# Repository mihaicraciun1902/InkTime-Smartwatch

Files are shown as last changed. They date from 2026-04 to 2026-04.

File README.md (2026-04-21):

# ⌚ InkTime: Open-Source Hackable Smartwatch

**InkTime** is an affordable, open-source smartwatch powered by the Nordic nRF52840 SoC and an ultra-low-power e-paper display. It is designed from the ground up to be highly hackable, easy to manufacture, and power-efficient.

This repository contains all Engineering Validation (EVT) and Design Validation (DVT) files, including schematics, PCB layouts, 3D mechanical models, and manufacturing files.

---

## 🏗️ 1. System Architecture (Block Diagram)

The following diagram illustrates the core components of the InkTime hardware and their data/power relationships:

```text
                     +---------------------------------------------------+
                     |               nRF52840 SoC (U$1)                  |
                     |          ARM Cortex-M4F @ 64 MHz                  |
                     |    BLE 5.0 | 1MB Flash | 256KB RAM | USB 2.0      |
                     +---------------------------------------------------+
                              |                 |                  |
       [ SPI & GPIO ]---------+                 |                  +--------[ I2C Bus ]
       |                                        |                  |
+-------------------+                           |           +-------------------+
| E-Paper Display   |                           |           | BQ25180 (Charger) |<-- USB VBUS
| 24-pin FPC (J2)   |                           |           +-------------------+
+-------------------+       [ Push Buttons ]----+           | MAX17048 (Fuel)   |<-- LiPo Cell
                            | SW_UP (P0.13)     |           +-------------------+
+-------------------+       | SW_ENT (P0.14)    |           | BMA423 (IMU)      |
| Power Management  |       | SW_DN (P1.02)     |           +-------------------+
| RT6160A 3.3V Reg. |       +-------------------+           | DRV2605 (Haptic)  |
+-------------------+                                       +-------------------+
```

## 🧩 2. Hardware Implementation & Functionality

The hardware is designed on a 1mm thick, 2-layer PCB to fit strictly within the mechanical constraints of the provided case. All component placement is restricted to the TOP layer, with dual ground planes and extensive via stitching.

### Core Processing & Connectivity (nRF52840)

The heart of the watch is the nRF52840-QIAA. It handles all BLE 5.0 communication, USB 2.0 Full-Speed interfacing, and peripheral management.

- **Clocks:** Requires a 32 MHz crystal (X1) for the RF HFXO and a 32.768 kHz crystal (X2) for the RTC/LFXO deep sleep timekeeping.
- **RF Layout:** The 2.4 GHz chip antenna (Johanson 2450AT18B100E) is edge-mounted. Per Nordic guidelines, the PCB is physically cut out directly beneath the antenna, with a strict keepout zone (no copper, no routing).

### Display System

We utilize an e-paper display connected via a 24-pin 0.5mm FPC connector.

- **Interface:** 4-wire SPI + GPIO control (DC, RST, BUSY).
- **Power:** Driven by an independent 3.3V boost converter (L1). Power is gated by a P-channel MOSFET (Q1) via the `EPD_PWR` pin, ensuring zero current draw when the display is not refreshing.

### Power Management & Battery (BQ25180 + RT6160A)

- **Charging:** The BQ25180 manages charging from the USB-C VBUS. It is compact and entirely I2C-configurable. The charge current is hardware-set to 100mA via a 10kΩ resistor.
- **Regulation:** The RT6160A buck-boost converter takes the variable LiPo voltage (3.0V - 4.2V) and provides a stable 3.3V system rail.
- **Clearance hack:** To meet strict Z-axis constraints of the case, the JST connector was omitted; the LiPo cell is soldered directly to `TP_VBAT` and `TP_BAT_GND`.

### Sensors & Actuators

- **IMU (BMA423):** A 3-axis accelerometer with a built-in hardware step counter and wrist-tilt detection. It uses hardware interrupts (`IMU_INT1`, `IMU_INT2`) to wake the nRF from deep sleep, saving processing power.
- **Haptics (DRV2605):** Drives an ERM/LRA vibration motor. The `HAPTIC_EN` pin physically disables the driver during sleep to eliminate quiescent current leakage.

## 📌 3. nRF52840 Pin Mapping

Pins were carefully selected to group peripheral buses (like SPI and I2C) physically close to their target ICs, minimizing trace lengths.

| Pin | Signal | Destination | Function & Justification |
|---|---|---|---|
| P0.02 | SCK | EPD (J2) | SPI Clock. SPIM is remappable; chosen for routing ease. |
| P0.03 | MOSI | EPD (J2) | SPI Data Out. Grouped with SCK to minimize trace length. |
| P0.05 | EPD_CS | EPD (J2) | SPI Chip Select for e-paper. |
| P0.06 | SDA | I2C Bus | I2C Data. Placed close to BQ25180 & BMA423 to keep traces short. |
| P0.07 | SCL | I2C Bus | I2C Clock. |
| P0.08 | IMU_INT1 | BMA423 | Hardware wake interrupt from accelerometer. |
| P0.11 | PMIC_INT | BQ25180 | Interrupt for battery charge state changes. |
| P0.12 | HAPTIC_EN | DRV2605 | GPIO output to hard-disable haptic driver during sleep. |
| P0.13 / P0.14 / P1.02 | SW_UP / ENT / DN  | Tactile Switches | GPIO inputs with hardware debouncing (10kΩ pull-up + 1µF low-pass). |
| P1.01 | EPD_PWR | Q1 Gate | EPD power rail enable switch. |

## 🔋 4. Power Consumption Analysis

The system is highly optimized for deep sleep. Based on component datasheets, estimated battery life on a 180mAh LiPo cell is approximately 5-7 days.

| Mode | nRF52840 | Display | Sensors/Other | Total |
|---|---|---|---|---|
| System OFF (Sleep) | 2.5 µA | 0 mA | 0.5 µA | ~3 µA |
| BLE Advertising (1s)  | ~15 mA | 0 mA | 0.13 mA | ~15 mA |
| Display Refresh | ~3 mA | ~30 mA  | 0.13 mA | ~33 mA |
| Haptic Feedback | ~5 mA | 0 mA | ~60 mA | ~65 mA |

## 🧾 5. Bill of Materials (BOM)

Updated from Fusion Hub partlist export (Project: **Proiect TSC**, Board: **PCB**, Date: **21/04/2026 4:52 PM**).

| Qty | Value / MPN | Device / Package | Parts | Description |
|-----|---|---|---|---|
| 1 | ESP32_C6_LIBRARY_7_JUMPER_SJ | ESP32_C6_LIBRARY_7_JUMPER_SJ | SJ1 | SMD solder jumper |
| 3 | 0 / CPF0201D7K68C1 | CPF0201D7K68C1_0201 | R2, R3, R4 | 7.68k thin film resistor, 0201 |
| 2 | 0.1uF / GRM011R60J152KE01L | CAPC0201X13N | C23, C42 | Murata capacitor |
| 3 | 0.1uF | NORDIC_NRF_3_RESC0201_L | C27, C34, EPD_C5 | Generic chip capacitor |
| 1 | 0.47 / CPF0201D7K68C1 | CPF0201D7K68C1_0201 | R1_EP_DR | 0201 thin film resistor |
| 1 | 1.0uF | NORDIC_NRF_3_RESC0201_L | C15 | Generic chip capacitor |
| 5 | 100nF | NORDIC_NRF_3_RESC0201_L | C5, C7, C8, C12, C19 | Generic chip capacitor |
| 1 | 100pF | NORDIC_NRF_3_RESC0201_L | C11 | Generic chip capacitor |
| 2 | 10K / CPF0201D7K68C1 | CPF0201D7K68C1_0201 | R2_EP_DR, R_PWR_EPD | 0201 thin film resistor |
| 4 | 10k / CPF0201D7K68C1 | CPF0201D7K68C1_0201 | R5, R7, R8, R9 | 0201 thin film resistor |
| 3 | 10uF | NORDIC_NRF_3_RESC0201_L | C1-EP-DR, C24, C39 | Generic chip capacitor |
| 1 | 10uH | NORDIC_NRF_2_RESC0402_L | L2 | Generic chip inductor |
| 4 | 12pF | NORDIC_NRF_3_RESC0201_L | C1, C2, C17, C18 | Generic chip capacitor |
| 1 | 15nH | NORDIC_NRF_2_RESC0402_L | L3 | Generic chip inductor |
| 2 | 1pF | NORDIC_NRF_3_RESC0201_L | C3, C4 | Generic chip capacitor |
| 2 | 1uF / GRM011R60J152KE01L | CAPC0201X13N | C37, C38 | Murata capacitor |
| 9 | 1uF | NORDIC_NRF_3_RESC0201_L | EPD_C1, EPD_C2, EPD_C6, EPD_C7, EPD_C8, EPD_C9, EPD_C10, EPD_C11, EPD_C12 | Generic chip capacitor |
| 4 | 1uF | NORDIC_NRF_3_RESC0402_L | C29, C30, C31, C32 | Generic chip capacitor |
| 1 | 2.2 / CPF0201D7K68C1 | CPF0201D7K68C1_0201 | R_TYPE_SEL | 0201 thin film resistor |
| 3 | EVP-AKE31A | SW_EVP-AKE31A_PAN | SW_DN, SW_ENT, SW_UP | Panasonic tactile switch |
| 1 | DMG2305UX-7 | SOT23-3 | Q1 | P-channel MOSFET (20V/4.2A/52mΩ) |
| 2 | 22uF | NORDIC_NRF_3_RESC0201_L | C25, C33 | Generic chip capacitor |
| 1 | 3.9nH | NORDIC_NRF_2_RESC0201_M | L1 | Generic chip inductor |
| 1 | 9HT10-32.768KDZF-T | XTAL330X1051X90N | X2 | 32.768kHz crystal |
| 1 | 32MHz | NORDIC_NRF_BT-XTAL_2016_N | X1 | 32MHz crystal |
| 2 | 3k3 / CPF0201D7K68C1 | CPF0201D7K68C1_0201 | R17, R18 | 0201 thin film resistor |
| 6 | 4.7uF | NORDIC_NRF_3_RESC0201_L | C2-EP-DR, C6, C14, C20, C21, C43 | Generic chip capacitor |
| 1 | 2450AT18B100E | ANTC3216X140N | ANT1 | 2.45GHz chip antenna |
| 1 | 47nF | NORDIC_NRF_3_RESC0201_L | C16 | Generic chip capacitor |
| 1 | 744043680 | IND_4828-WE-TPC_WRE | L5 | Wurth inductor, 48uH |
| 1 | 503480-2400 | 5034802400 | J1 | 24-pin 0.5mm FPC connector |
| 2 | 5k1 / CPF0201D7K68C1 | CPF0201D7K68C1_0201 | R1_USB, R2_USB | 0201 thin film resistor |
| 1 | 820pF | NORDIC_NRF_3_RESC0201_L | C9 | Generic chip capacitor |
| 1 | BMA423 | BMA423_BMA423 | IC3 | 3-axis accelerometer |
| 1 | BQ25180YBGR | BGA8C40P2X4_100X155X50 | IC1 | Li-ion/LiFePO4 charger IC |
| 1 | FTC252012SR47MBCA | INDC2016X100N | L7 | 0.47uH inductor |
| 14 | HECTOR_WATCH_1_TPTP20R | HECTOR_WATCH_1_TP20R | TP_3.3V, TP_3V3, TP_BAT_GND, TP_GND, TP_ON, TP_OP, TP_RESET, TP_SCL, TP_SDA, TP_SWDIO, TP_SWD_CLK, TP_SWO, TP_VBAT, TP_VREG | Test pads |
| 1 | KH-TYPE-C-16P | KH-TYPE-C-16P_KINGHELM_KH-TYPE-C-16P | J4 | USB-C 16-pin connector |
| 1 | MAX17048G+T10 | SON50P200X200X80-9N | U3 | 1-cell/2-cell fuel gauge |
| 3 | MBR0530 | SOD3716X135N | D2, D4, D5 | Schottky diode 30V 0.5A |
| 3 | N.C. | NORDIC_NRF_3_RESC0201_L | C10, C13, C22 | DNI capacitor footprints |
| 1 | NRF52840_QF | AQFN50P700X700X85_HS-74N | U1 | nRF52840 SoC |
| 1 | RT6160AWSC | BGA15C40P3X5_140X230X60 | IC9 | Buck-boost regulator |
| 1 | DRV2605YZFR | BGA9C50P3X3_144X144X62 | IC2 | Haptic driver |
| 1 | SI1308EDL-T1-GE3 | SOT65P210X110-3N | Q3 | N-channel MOSFET |
| 1 | TC2030-IDC | TC2030IDC | J2 | 6-pos cable adapter |
| 1 | USBLC6-2SC6Y | SOT95P280X145-6N | D3 | USB ESD TVS protection array |

## 🛠️ 6. Design Log & Constraint Compliance (Review Notes)

This design strictly follows the DVT guidelines and mechanical constraints. Below are key design decisions and ignored rule exceptions intended for the reviewer:

- **1mm PCB thickness:** Reduced from standard 1.6mm to ensure vertical mechanical clearance inside the provided STEP case.
- **TOP-layer-only placement:** All SMDs and ICs are strictly placed on the TOP layer. Both layers feature grounded copper pours, heavily via-stitched (especially near the RF path).
- **Trace widths & geometry:** Power nets (`3V3`, `VBAT`, `VBUS`, `VREG`) are routed at 0.3mm. Data signals use 0.15mm. Trace neck-down is only utilized under BGA pads. 90-degree angles were avoided; all corners use 45-degree chamfers.
- **Decoupling proximity:** Every 100nF decoupling capacitor is placed immediately adjacent (within one pad length) to its respective IC power pin on the TOP layer.
- **RF keepout & substrate:** The area under the 2450AT18B100E antenna is entirely void of copper on both layers, and features a physical PCB cutout per Nordic reference design.
- **Accepted ERC warning:** "Only INPUT pins on NET ID" is present but ignored as a known false-positive in the CAD tool, approved by project guidelines.
- **Accepted DRC errors:** Dimension errors near the three tactile buttons and the USB-C aperture are intentional structural slots required for casing alignment.
- **Silkscreen integrity:** Test pads (`TP_3V3`, `TP_SWDIO`, etc.) are clearly labeled in silkscreen. Component values are hidden to maintain a clean, readable layout.

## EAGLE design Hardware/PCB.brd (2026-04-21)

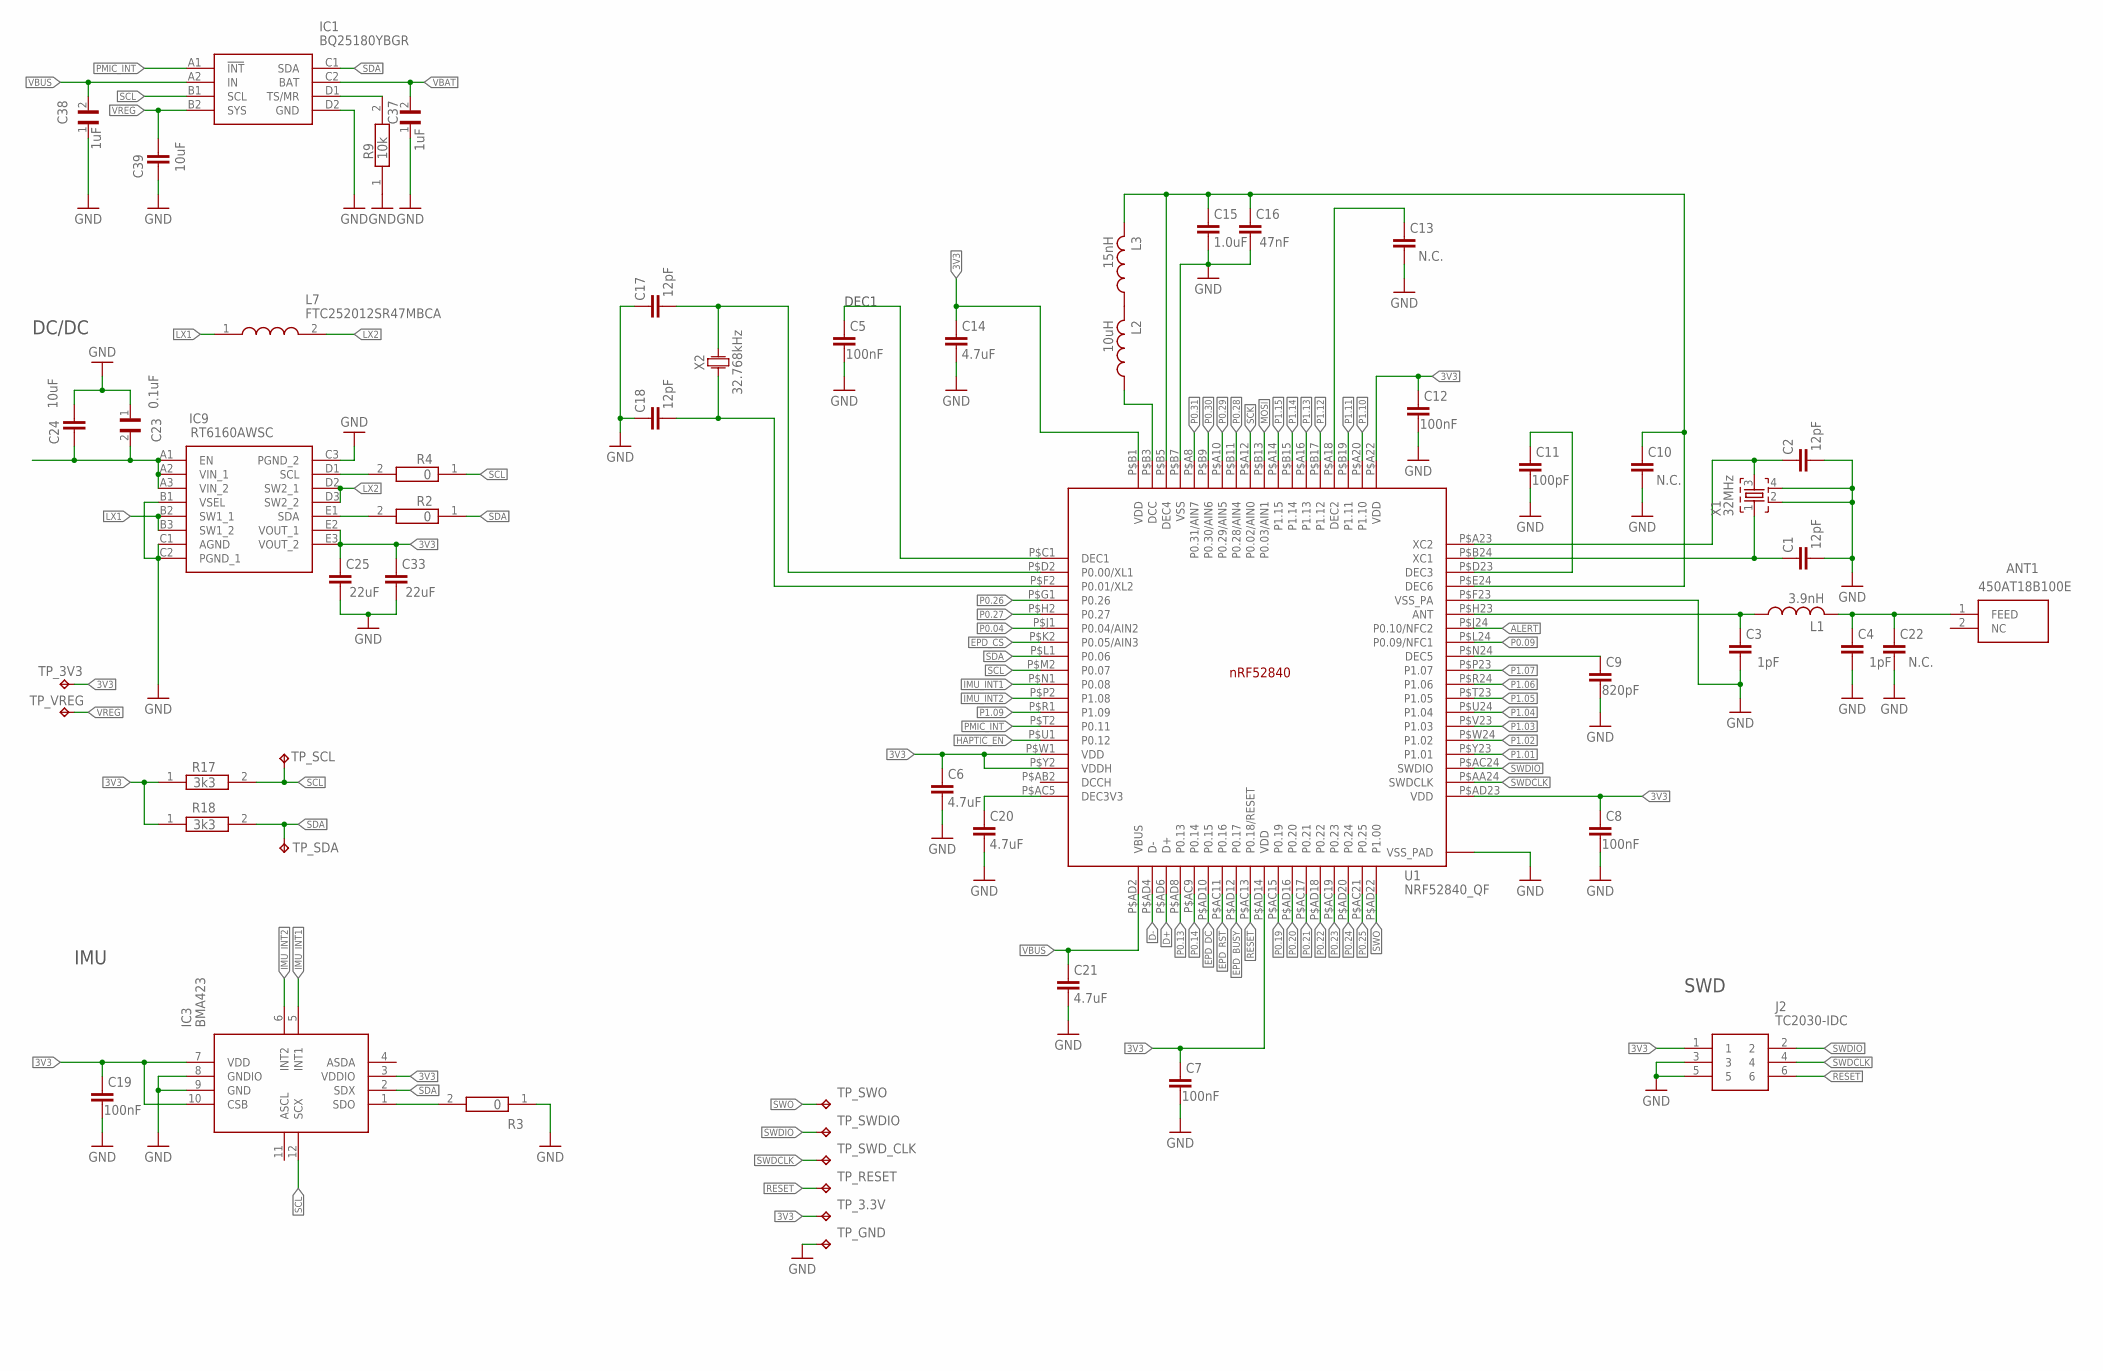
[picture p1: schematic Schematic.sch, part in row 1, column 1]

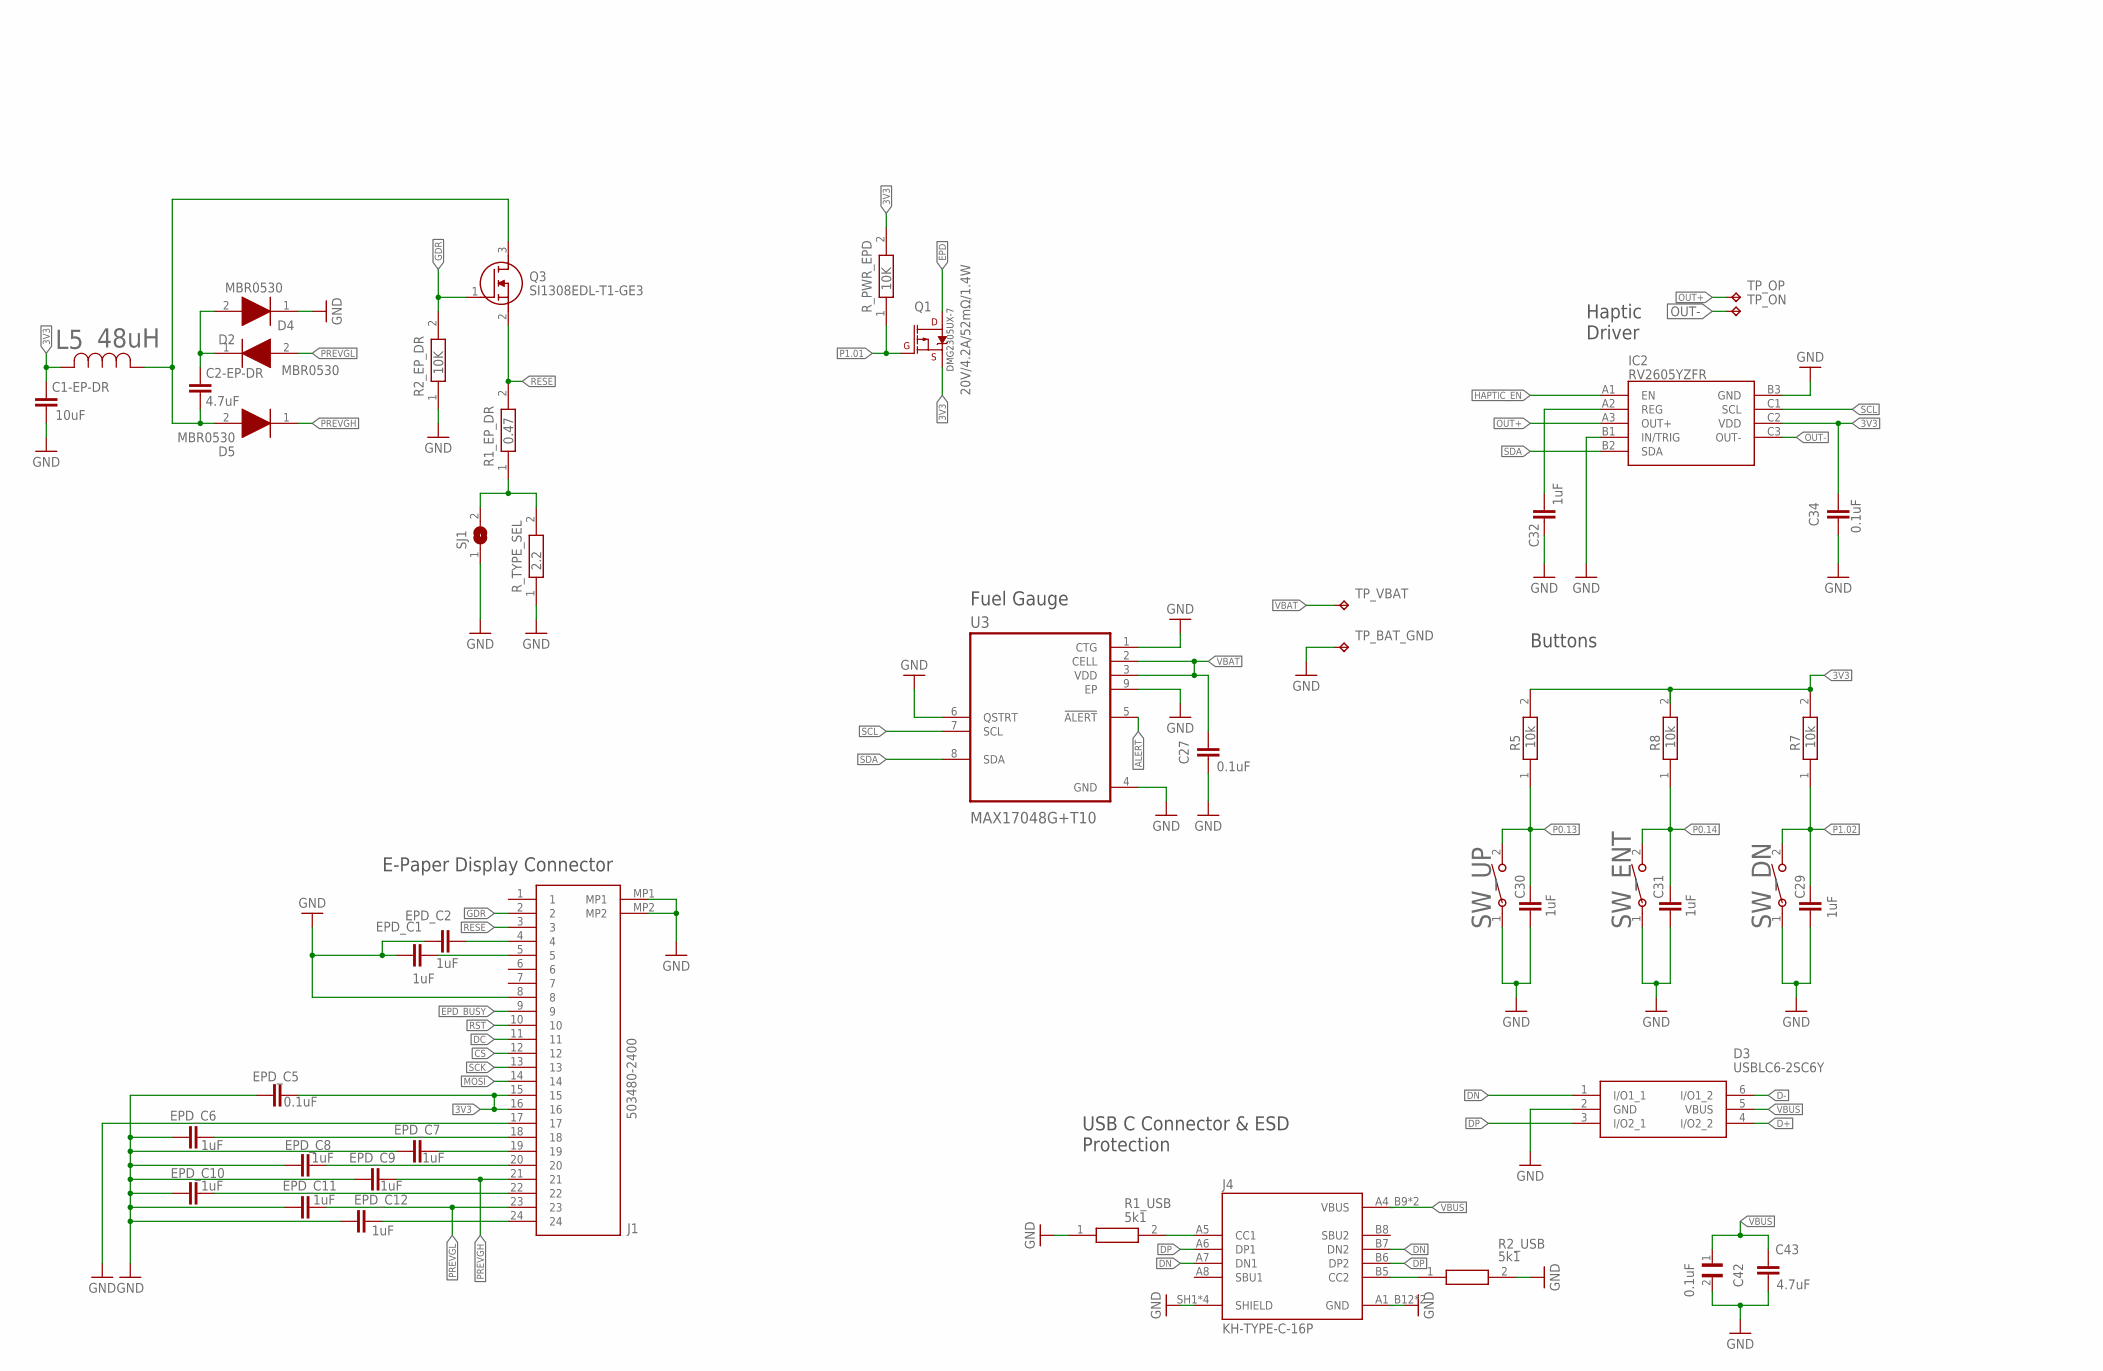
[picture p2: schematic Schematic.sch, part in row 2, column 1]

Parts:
ANT1: 450AT18B100E; 2450AT18B100E_ANTC3216X140N
C1, C2, C17, C18: 12pF; NORDIC_NRF_3_RESC0201_L
C1-EP-DR, C24, C39: 10uF; NORDIC_NRF_3_RESC0201_L
C2-EP-DR, C6, C14, C20, C21, C43: 4.7uF; NORDIC_NRF_3_RESC0201_L
C3, C4: 1pF; NORDIC_NRF_3_RESC0201_L
C5, C7, C8, C12, C19: 100nF; NORDIC_NRF_3_RESC0201_L
C9: 820pF; NORDIC_NRF_3_RESC0201_L
C10, C13, C22: N.C.; NORDIC_NRF_3_RESC0201_L
C11: 100pF; NORDIC_NRF_3_RESC0201_L
C15: 1.0uF; NORDIC_NRF_3_RESC0201_L
C16: 47nF; NORDIC_NRF_3_RESC0201_L
C23, C42: 0.1uF; GRM011R60J152KE01L_2_CAPC0201X13N
C25, C33: 22uF; NORDIC_NRF_3_RESC0201_L
C27, C34: 0.1uF; NORDIC_NRF_3_RESC0201_L
C29, C30, C31, C32: 1uF; NORDIC_NRF_3_RESC0402_L
C37, C38: 1uF; GRM011R60J152KE01L_2_CAPC0201X13N
D2, D4, D5: MBR0530; ESP32_C6_LIBRARY_5_SOD3716X135N
D3: USBLC6-2SC6Y; ESP32_C6_LIBRARY_3_SOT95P280X145-6N
EPD_C1, EPD_C2, EPD_C6, EPD_C7, EPD_C8, EPD_C9, EPD_C10, EPD_C11, EPD_C12: 1uF; NORDIC_NRF_3_RESC0201_L
EPD_C5: 0.1uF; NORDIC_NRF_3_RESC0201_L
IC1: BQ25180YBGR; BQ25180YBGR_BGA8C40P2X4_100X155X50
IC2: RV2605YZFR; DRV2605YZFR_BGA9C50P3X3_144X144X62
IC3: BMA423; BMA423_BMA423
IC9: RT6160AWSC; RT6160AWSC_BGA15C40P3X5_140X230X60
J1: 503480-2400; 503480-2400_5034802400
J2: TC2030-IDC; TC2030-IDC_TC2030IDC
J4: KH-TYPE-C-16P; KH-TYPE-C-16P_KINGHELM_KH-TYPE-C-16P
L1: 3.9nH; NORDIC_NRF_2_RESC0201_M
L2: 10uH; NORDIC_NRF_2_RESC0402_L
L3: 15nH; NORDIC_NRF_2_RESC0402_L
L5: 48uH; ESP32_C6_LIBRARY_2_IND_4828-WE-TPC_WRE
L7: FTC252012SR47MBCA; MLP2016SR47MT0S1_INDC2016X100N
Q1: 20V/4.2A/52mΩ/1.4W; ESP32_C6_LIBRARY_4_ESP32_C6_LIBRARY_4_ESP32_C6_LIBRARY_4_ES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
Q3: SI1308EDL-T1-GE3; ESP32_C6_LIBRARY_6_SOT65P210X110-3N
R1_EP_DR: 0.47; CPF0201D7K68C1_0201
R1_USB, R2_USB: 5k1; CPF0201D7K68C1_0201
R2, R3, R4: 0; CPF0201D7K68C1_0201
R2_EP_DR: 10K; CPF0201D7K68C1_0201
R5, R7, R8, R9: 10k; CPF0201D7K68C1_0201
R17, R18: 3k3; CPF0201D7K68C1_0201
R_PWR_EPD: 10K; CPF0201D7K68C1_0201
R_TYPE_SEL: 2.2; CPF0201D7K68C1_0201
SJ1: ESP32_C6_LIBRARY_7_JUMPER_SJ
SW_DN: 2025-10-22_07-23-44_LIBRARY_EVP-AKE31ASW_EVP-AKE3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; 2025-10-22_07-23-44_LIBRARY_SW_EVP-AKE31A_PAN
SW_ENT: 2025-10-22_07-23-44_LIBRARY_EVP-AKE31ASW_EVP-AKE3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; 2025-10-22_07-23-44_LIBRARY_SW_EVP-AKE31A_PAN
SW_UP: 2025-10-22_07-23-44_LIBRARY_EVP-AKE31ASW_EVP-AKE3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; 2025-10-22_07-23-44_LIBRARY_SW_EVP-AKE31A_PAN
TP_3.3V, TP_3V3: HECTOR_WATCH_1_TPTP20R; HECTOR_WATCH_1_TP20R
TP_BAT_GND: HECTOR_WATCH_1_TPTP20R; HECTOR_WATCH_1_TP20R
TP_GND: HECTOR_WATCH_1_TPTP20R; HECTOR_WATCH_1_TP20R
TP_ON: HECTOR_WATCH_1_TPTP20R; HECTOR_WATCH_1_TP20R
TP_OP: HECTOR_WATCH_1_TPTP20R; HECTOR_WATCH_1_TP20R
TP_RESET: HECTOR_WATCH_1_TPTP20R; HECTOR_WATCH_1_TP20R
TP_SCL: HECTOR_WATCH_1_TPTP20R; HECTOR_WATCH_1_TP20R
TP_SDA: HECTOR_WATCH_1_TPTP20R; HECTOR_WATCH_1_TP20R
TP_SWDIO: HECTOR_WATCH_1_TPTP20R; HECTOR_WATCH_1_TP20R
TP_SWD_CLK: HECTOR_WATCH_1_TPTP20R; HECTOR_WATCH_1_TP20R
TP_SWO: HECTOR_WATCH_1_TPTP20R; HECTOR_WATCH_1_TP20R
TP_VBAT: HECTOR_WATCH_1_TPTP20R; HECTOR_WATCH_1_TP20R
TP_VREG: HECTOR_WATCH_1_TPTP20R; HECTOR_WATCH_1_TP20R
U1: NRF52840_QF; NORDIC_NRF_4_AQFN50P700X700X85_HS-74N
U3: MAX17048G+T10; ESP32_C6_LIBRARY_SON50P200X200X80-9N
X1: 32MHz; NORDIC_NRF_BT-XTAL_2016_N
X2: 32.768kHz; XTAL330X1051X90N

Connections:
3V3: C1-EP-DR.2, C6.2, C7.2, C8.2, C12.2, C14.2, C19.2, C25.2, C33.2, C34.1, EPD_C5.2, IC2.C2 (VDD), IC3.3 (VDDIO), IC3.7 (VDD), IC3.10 (CSB), IC9.E2 (VOUT_1), IC9.E3 (VOUT_2), J1.15, J1.16, J2.1, L5.2, Q1.2 (S), R5.2, R7.2, R8.2, R17.1, R18.1, R_PWR_EPD.2, TP_3.3V.TP, TP_3V3.TP, U1.P$A22 (VDD), U1.P$AD14 (VDD), U1.P$AD23 (VDD), U1.P$B1 (VDD), U1.P$W1 (VDD), U1.P$Y2 (VDDH)
ALERT: U1.P$J24 (P0.10/NFC2), U3.5 (!ALERT)
CS: J1.12
D+: D3.4 (I/O2_2), U1.P$AD6 (D+)
D-: D3.6 (I/O1_2), U1.P$AD4 (D-)
DC: J1.11
DN: D3.1 (I/O1_1), J4.A7 (DN1), J4.B7 (DN2)
DP: D3.3 (I/O2_1), J4.A6 (DP1), J4.B6 (DP2)
EPD: Q1.3 (D)
EPD_BUSY: J1.9, U1.P$AD12 (P0.17)
EPD_CS: U1.P$K2 (P0.05/AIN3)
EPD_DC: U1.P$AD10 (P0.15)
EPD_RST: U1.P$AC11 (P0.16)
GDR: J1.2, Q3.1 (G), R2_EP_DR.2
GND: C1.1, C1-EP-DR.1, C2.1, C3.1, C4.1, C5.1, C6.1, C7.1, C8.1, C9.1, C10.1, C11.1, C12.1, C13.1, C14.1, C15.1, C16.1, C17.2, C18.2, C19.1, C20.1, C21.1, C22.1, C23.1, C24.2, C25.1, C27.2, C29.2, C30.2, C31.2, C32.2, C33.1, C34.2, C37.1, C38.1, C39.1, C42.2, C43.2, D2.1 (K), D3.2 (GND), EPD_C1.1, EPD_C2.1, EPD_C5.1, EPD_C6.1, EPD_C7.1, EPD_C8.1, EPD_C9.1, EPD_C10.1, EPD_C11.1, EPD_C12.1, IC1.D2 (GND), IC2.B1 (IN/TRIG), IC2.B3 (GND), IC3.8 (GNDIO), IC3.9 (GND), IC9.B1 (VSEL), IC9.C1 (AGND), IC9.C2 (PGND_1), IC9.C3 (PGND_2), J1.8, J1.17, J1.MP1, J1.MP2, J2.3, J2.5, J4.A1_B12 (GND), J4.A12_B1 (GND), J4.SH1 (SHIELD), J4.SH2 (SHIELD), J4.SH3 (SHIELD), J4.SH4 (SHIELD), R1_USB.1, R2_EP_DR.1, R2_USB.2, R3.1, R9.1, R_TYPE_SEL.1, SJ1.1, SW_DN.1, SW_ENT.1, SW_UP.1, TP_BAT_GND.TP, TP_GND.TP, U1.P$74 (VSS_PAD), U1.P$75 (VSS_PAD), U1.P$76 (VSS_PAD), U1.P$77 (VSS_PAD), U1.P$78 (VSS_PAD), U1.P$79 (VSS_PAD), U1.P$80 (VSS_PAD), U1.P$81 (VSS_PAD), U1.P$82 (VSS_PAD), U1.P$83 (VSS_PAD), U1.P$84 (VSS_PAD), U1.P$85 (VSS_PAD), U1.P$86 (VSS_PAD), U1.P$87 (VSS_PAD), U1.P$88 (VSS_PAD), U1.P$89 (VSS_PAD), U1.P$90 (VSS_PAD), U1.P$B7 (VSS), U1.P$F23 (VSS_PA), U3.1 (CTG), U3.4 (GND), U3.6 (QSTRT), U3.9 (EP), X1.2, X1.4
HAPTIC_EN: IC2.A1 (EN), U1.P$U1 (P0.12)
IMU_INT1: IC3.5 (INT1), U1.P$N1 (P0.08)
IMU_INT2: IC3.6 (INT2), U1.P$P2 (P1.08)
LX1: IC9.B2 (SW1_1), IC9.B3 (SW1_2), L7.1
LX2: IC9.D2 (SW2_1), IC9.D3 (SW2_2), L7.2
MOSI: J1.14, U1.P$B13 (P0.03/AIN1)
unnamed: ANT1.1 (FEED), C4.2, C22.2, L1.2
unnamed: L2.2, L3.1
unnamed: J4.A5 (CC1), R1_USB.2
unnamed: C32.1, IC2.A2 (REG)
unnamed: C31.1, R8.1, SW_ENT.2
unnamed: C29.1, R7.1, SW_DN.2
unnamed: EPD_C6.2, J1.18
unnamed: EPD_C7.2, J1.19
unnamed: EPD_C2.2, J1.4
unnamed: EPD_C8.2, J1.20
unnamed: J4.B5 (CC2), R2_USB.1
unnamed: EPD_C1.2, J1.5
unnamed: C2-EP-DR.1, D5.2 (A), L5.1, Q3.3 (D)
unnamed: EPD_C10.2, J1.22
unnamed: C2-EP-DR.2, D2.2 (A), D4.1 (K)
unnamed: EPD_C12.2, J1.24
unnamed: R1_EP_DR.1, R_TYPE_SEL.2, SJ1.2
unnamed: IC9.D1 (SCL), R4.2
unnamed: IC9.E1 (SDA), R2.2
unnamed: L2.1, U1.P$B3 (DCC)
unnamed: C23.2, C24.1, IC9.A1 (EN), IC9.A2 (VIN_1), IC9.A3 (VIN_2)
unnamed: IC3.1 (SDO), R3.2
unnamed: C13.2, U1.P$A18 (DEC2)
unnamed: C10.2, C15.2, C16.2, L3.2, U1.P$B5 (DEC4), U1.P$E24 (DEC6)
unnamed: C5.2, U1.P$C1 (DEC1)
unnamed: C17.1, U1.P$D2 (P0.00/XL1), X2.2
unnamed: IC1.D1 (TS/MR), R9.2
unnamed: C18.1, U1.P$F2 (P0.01/XL2), X2.1
unnamed: C20.2, U1.P$AC5 (DEC3V3)
unnamed: C9.2, U1.P$N24 (DEC5)
unnamed: C11.2, U1.P$D23 (DEC3)
unnamed: C3.2, L1.1, U1.P$H23 (ANT)
unnamed: C1.2, U1.P$B24 (XC1), X1.1
unnamed: C2.2, U1.P$A23 (XC2), X1.3
OUT+: IC2.A3 (OUT+), TP_OP.TP
OUT-: IC2.C3 (OUT-), TP_ON.TP
P0.04: U1.P$J1 (P0.04/AIN2)
P0.09: U1.P$L24 (P0.09/NFC1)
P0.13: C30.1, R5.1, SW_UP.2, U1.P$AD8 (P0.13)
P0.14: U1.P$AC9 (P0.14)
P0.19: U1.P$AC15 (P0.19)
P0.20: U1.P$AD16 (P0.20)
P0.21: U1.P$AC17 (P0.21)
P0.22: U1.P$AD18 (P0.22)
P0.23: U1.P$AC19 (P0.23)
P0.24: U1.P$AD20 (P0.24)
P0.25: U1.P$AC21 (P0.25)
P0.26: U1.P$G1 (P0.26)
P0.27: U1.P$H2 (P0.27)
P0.28: U1.P$B11 (P0.28/AIN4)
P0.29: U1.P$A10 (P0.29/AIN5)
P0.30: U1.P$B9 (P0.30/AIN6)
P0.31: U1.P$A8 (P0.31/AIN7)
P1.01: Q1.1 (G), R_PWR_EPD.1, U1.P$Y23 (P1.01)
P1.02: U1.P$W24 (P1.02)
P1.03: U1.P$V23 (P1.03)
P1.04: U1.P$U24 (P1.04)
P1.05: U1.P$T23 (P1.05)
P1.06: U1.P$R24 (P1.06)
P1.07: U1.P$P23 (P1.07)
P1.09: U1.P$R1 (P1.09)
P1.10: U1.P$A20 (P1.10)
P1.11: U1.P$B19 (P1.11)
P1.12: U1.P$B17 (P1.12)
P1.13: U1.P$A16 (P1.13)
P1.14: U1.P$B15 (P1.14)
P1.15: U1.P$A14 (P1.15)
PMIC_INT: IC1.A1 (!INT), U1.P$T2 (P0.11)
PREVGH: D5.1 (K), EPD_C9.2, J1.21
PREVGL: D4.2 (A), EPD_C11.2, J1.23
RESE: J1.3, Q3.2 (S), R1_EP_DR.2
RESET: J2.6, TP_RESET.TP, U1.P$AC13 (P0.18/RESET)
RST: J1.10
SCK: J1.13, U1.P$A12 (P0.02/AIN0)
SCL: IC1.B1 (SCL), IC2.C1 (SCL), IC3.12 (SCX), R4.1, R17.2, TP_SCL.TP, U1.P$M2 (P0.07), U3.7 (SCL)
SDA: IC1.C1 (SDA), IC2.B2 (SDA), IC3.2 (SDX), R2.1, R18.2, TP_SDA.TP, U1.P$L1 (P0.06), U3.8 (SDA)
SWDCLK: J2.4, TP_SWD_CLK.TP, U1.P$AA24 (SWDCLK)
SWDIO: J2.2, TP_SWDIO.TP, U1.P$AC24 (SWDIO)
SWO: TP_SWO.TP, U1.P$AD22 (P1.00)
VBAT: C27.1, C37.2, IC1.C2 (BAT), TP_VBAT.TP, U3.2 (CELL), U3.3 (VDD)
VBUS: C21.2, C38.2, C42.1, C43.1, D3.5 (VBUS), IC1.A2 (IN), J4.A4_B9 (VBUS), J4.A9_B4 (VBUS), U1.P$AD2 (VBUS)
VREG: C39.2, IC1.B2 (SYS), TP_VREG.TP

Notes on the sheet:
Fuel Gauge
Haptic Driver
Buttons
DMG2305UX-7
USB C Connector & ESD Protection
E-Paper Display Connector
IMU
SWD
DC/DC
DEC1

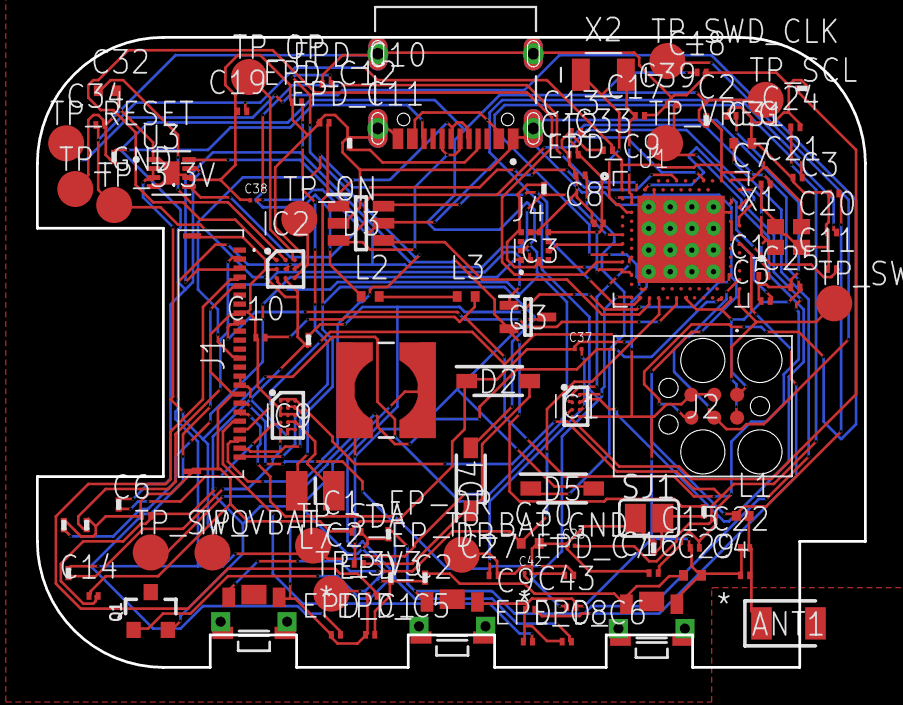
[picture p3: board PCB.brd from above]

Board: 2 copper layers, 46.0 x 35.0 mm, 105 parts (0 on the bottom side), 67 nets.

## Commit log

2026-04-21 Add files via upload
    updated schematic and pcb
    [PCB.brd, Schematic.sch]
2026-04-21 Enhance README with detailed project information
    Expanded the README to include detailed information about the InkTime smartwatch, including system architecture, hardware implementation, power consumption analysis, and a bill of materials.

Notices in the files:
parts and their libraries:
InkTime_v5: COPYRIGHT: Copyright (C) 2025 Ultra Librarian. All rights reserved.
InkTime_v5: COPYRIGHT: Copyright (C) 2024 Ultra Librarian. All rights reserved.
